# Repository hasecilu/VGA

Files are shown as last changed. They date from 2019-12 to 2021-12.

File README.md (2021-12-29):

# VGA adapter
This is a simple PCB board for interfacing a FPGA with SIL header to a VGA connector to add video functionalities to your projects.
Designed with [KiCad](https://kicad.org/download/)

[Download here](https://gitlab.com/hasecilu/VGA/-/archive/master/VGA-master.zip)

## Important!

For updates go to the [GitLab repo](https://gitlab.com/hasecilu/VGA)

## Pictures

First render
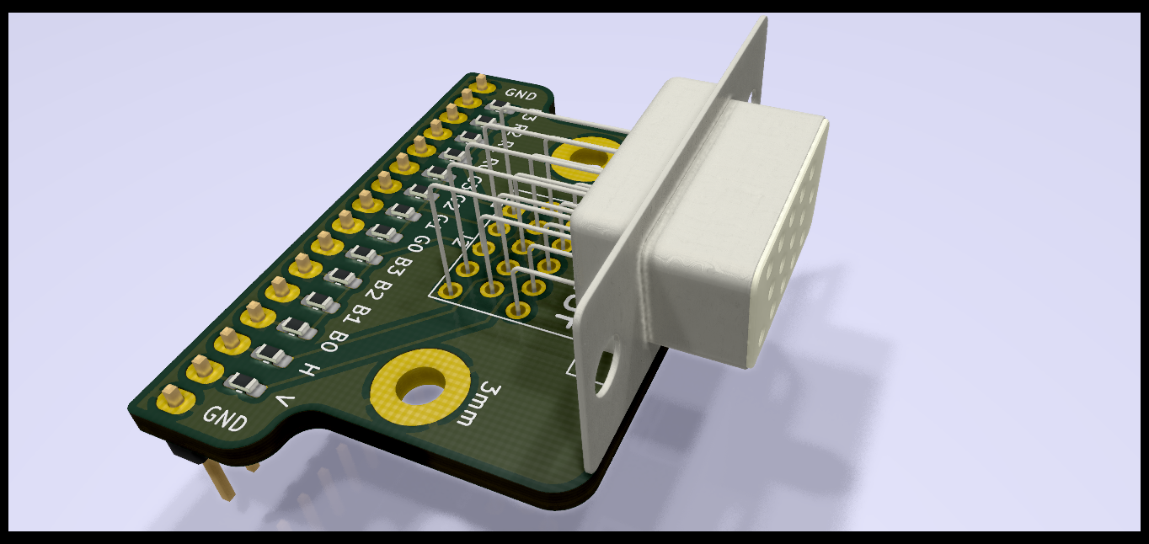
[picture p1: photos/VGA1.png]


Second render
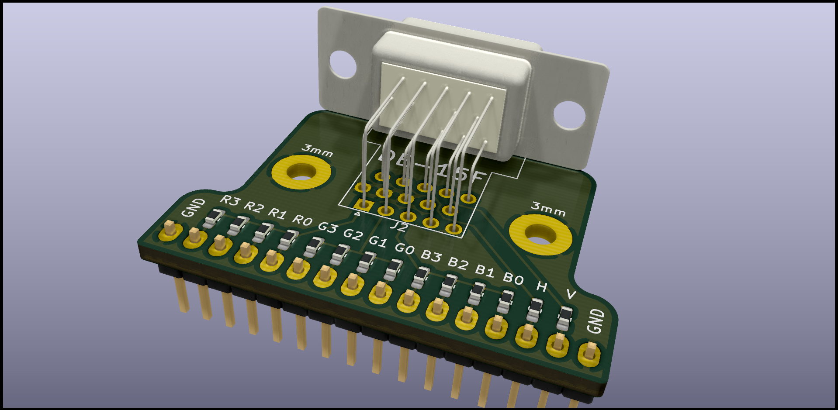
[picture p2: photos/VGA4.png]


Third render
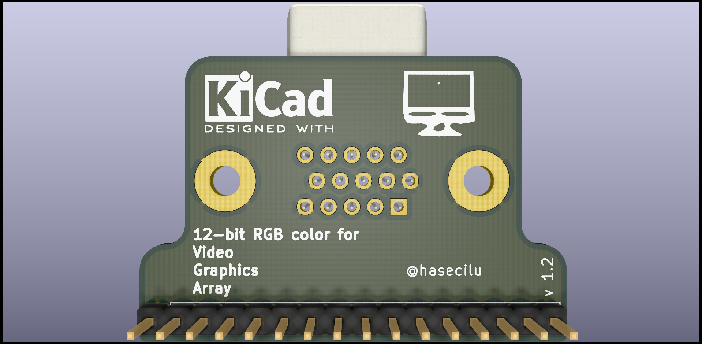
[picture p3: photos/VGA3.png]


Fourth render
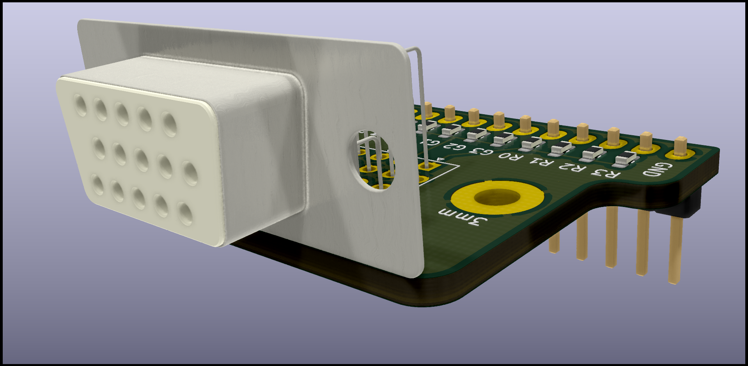
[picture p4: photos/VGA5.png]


Please note that the VGA board showed in the next pictures are from an older version and that's the reason there is a cable for connecting ground.
The new version has ground pins on both sides to avoid use cables (generally ground pins are at the begin/end of one SIL header in the development boards).

Perspective view
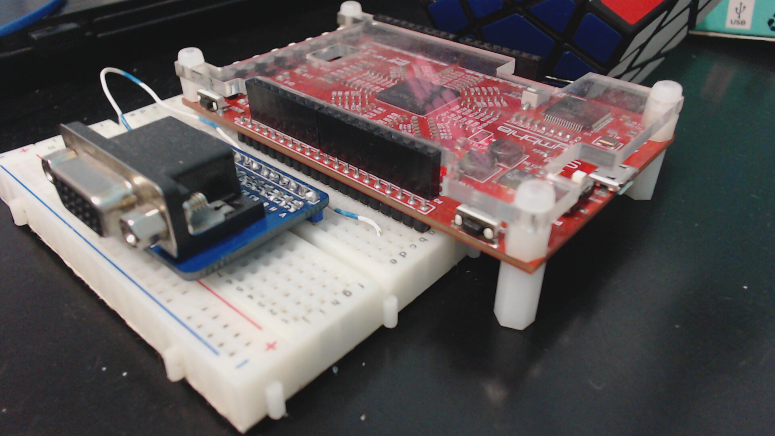
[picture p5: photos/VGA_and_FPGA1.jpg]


Top view
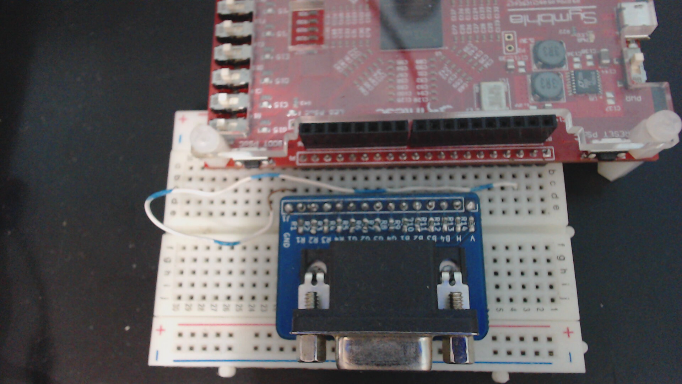
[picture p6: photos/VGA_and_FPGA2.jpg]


## Using the PCB

KiCad render (https://www.youtube.com/watch?v=zfjPtc4_cl0)

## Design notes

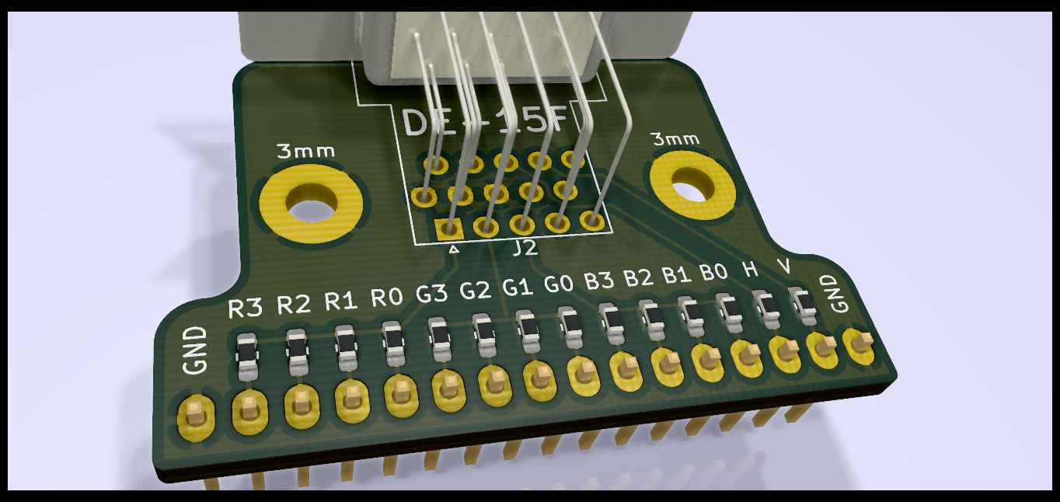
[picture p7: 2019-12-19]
photos/VGA2.png

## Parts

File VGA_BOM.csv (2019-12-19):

Source: | /home/uli/Documents/KiCAD/Boards/VGA/VGA.sch
Date: | Fri 13 Dec 2019 15:05:54 CST
Tool: | Eeschema 5.1.5-52549c5~84~ubuntu18.04.1
Generator: | /usr/share/kicad/plugins/bom_csv_grouped_by_value.py
Component Count: | 16
Individual Components:
Item | Qty | Reference(s) | Value | LibPart | Footprint | Datasheet
 |  | J1 | Conn_01x16 | Connector_Generic:Conn_01x16 | Connector_PinHeader_2.54mm:PinHeader_1x16_P2.54mm_Vertical | ~
 |  | J2 | DB15_Female_HighDensity | Connector:DB15_Female_HighDensity | Connector_Dsub:DSUB-15-HD_Female_Horizontal_P2.29x2.54mm_EdgePinOffset9.40mm | ~
 |  | R1 | 510 | Device:R | Resistor_SMD:R_0603_1608Metric_Pad1.05x0.95mm_HandSolder | ~
 |  | R2 | 1k | Device:R | Resistor_SMD:R_0603_1608Metric_Pad1.05x0.95mm_HandSolder | ~
 |  | R3 | 2k | Device:R | Resistor_SMD:R_0603_1608Metric_Pad1.05x0.95mm_HandSolder | ~
 |  | R4 | 4k | Device:R | Resistor_SMD:R_0603_1608Metric_Pad1.05x0.95mm_HandSolder | ~
 |  | R5 | 510 | Device:R | Resistor_SMD:R_0603_1608Metric_Pad1.05x0.95mm_HandSolder | ~
 |  | R6 | 1k | Device:R | Resistor_SMD:R_0603_1608Metric_Pad1.05x0.95mm_HandSolder | ~
 |  | R7 | 2k | Device:R | Resistor_SMD:R_0603_1608Metric_Pad1.05x0.95mm_HandSolder | ~
 |  | R8 | 4k | Device:R | Resistor_SMD:R_0603_1608Metric_Pad1.05x0.95mm_HandSolder | ~
 |  | R9 | 510 | Device:R | Resistor_SMD:R_0603_1608Metric_Pad1.05x0.95mm_HandSolder | ~
 |  | R10 | 1k | Device:R | Resistor_SMD:R_0603_1608Metric_Pad1.05x0.95mm_HandSolder | ~
 |  | R11 | 2k | Device:R | Resistor_SMD:R_0603_1608Metric_Pad1.05x0.95mm_HandSolder | ~
 |  | R12 | 4k | Device:R | Resistor_SMD:R_0603_1608Metric_Pad1.05x0.95mm_HandSolder | ~
 |  | R13 | 82 | Device:R | Resistor_SMD:R_0603_1608Metric_Pad1.05x0.95mm_HandSolder | ~
 |  | R14 | 82 | Device:R | Resistor_SMD:R_0603_1608Metric_Pad1.05x0.95mm_HandSolder | ~
Collated Components:
Item | Qty | Reference(s) | Value | LibPart | Footprint | Datasheet
1 | 1 | J1 | Conn_01x16 | Connector_Generic:Conn_01x16 | Connector_PinHeader_2.54mm:PinHeader_1x16_P2.54mm_Vertical | ~
2 | 1 | J2 | DB15_Female_HighDensity | Connector:DB15_Female_HighDensity | Connector_Dsub:DSUB-15-HD_Female_Horizontal_P2.29x2.54mm_EdgePinOffset9.40mm | ~
3 | 3 | R1, R5, R9 | 510 | Device:R | Resistor_SMD:R_0603_1608Metric_Pad1.05x0.95mm_HandSolder | ~
4 | 3 | R2, R6, R10 | 1k | Device:R | Resistor_SMD:R_0603_1608Metric_Pad1.05x0.95mm_HandSolder | ~
5 | 3 | R3, R7, R11 | 2k | Device:R | Resistor_SMD:R_0603_1608Metric_Pad1.05x0.95mm_HandSolder | ~
6 | 3 | R4, R8, R12 | 4k | Device:R | Resistor_SMD:R_0603_1608Metric_Pad1.05x0.95mm_HandSolder | ~
7 | 2 | R13, R14 | 82 | Device:R | Resistor_SMD:R_0603_1608Metric_Pad1.05x0.95mm_HandSolder | ~

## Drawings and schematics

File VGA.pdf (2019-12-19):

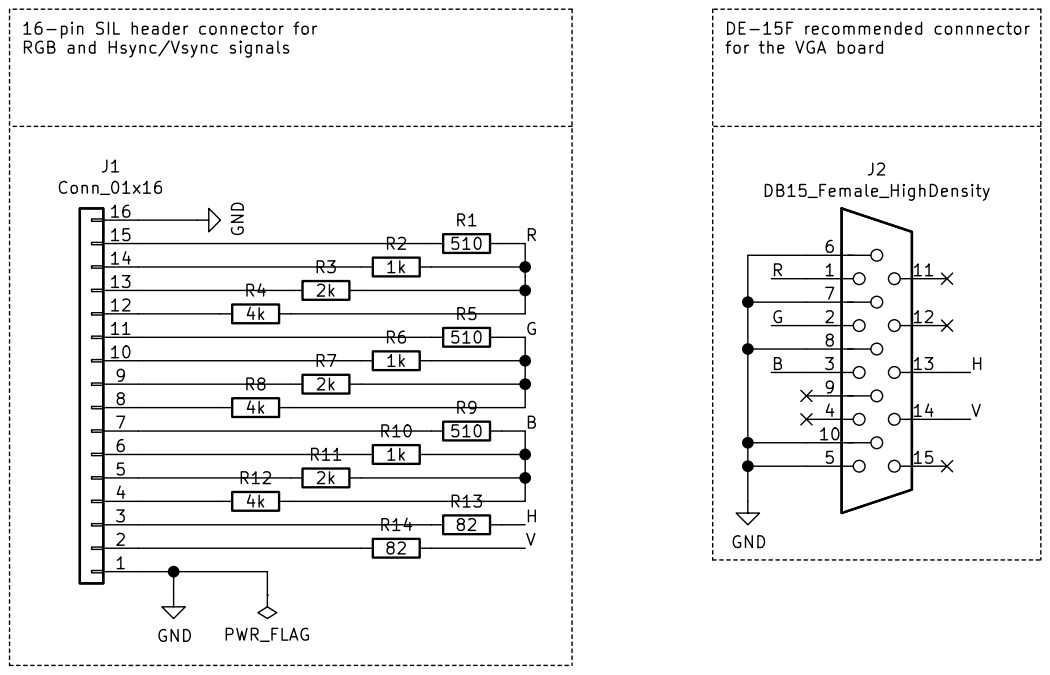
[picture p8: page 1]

16-pin SIL header connector for
RGB and Hsync/Vsync signals

V DE-15F recommended connnector
for the VGA board

12 bits per pixel (bpp) 2¹²=4096 different colors R4

2=16 different red, green and blue tonalities
4 bits per color channel/sample (bps)
File: VGA.sch Sheet: / Ulices AH

Id: 1/1 Title: 12-bit RGB color for VGA module / 4-bit color depth

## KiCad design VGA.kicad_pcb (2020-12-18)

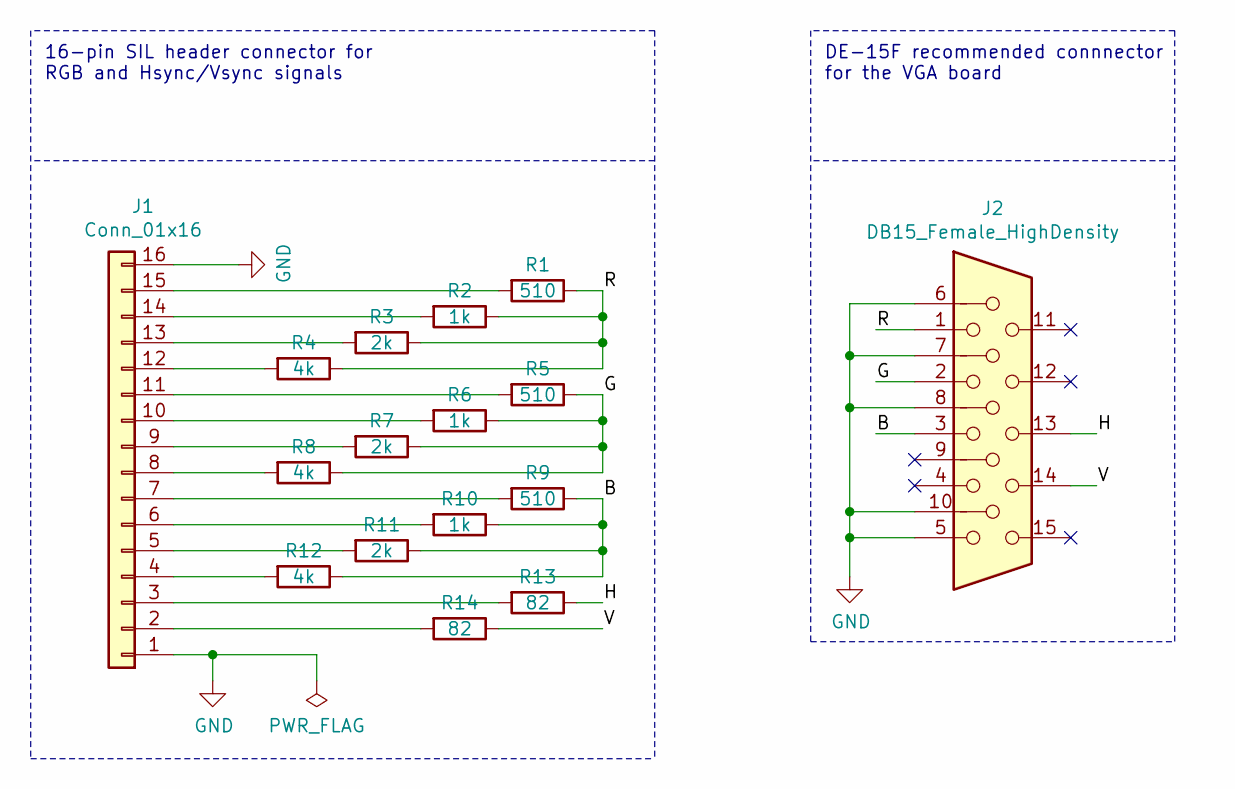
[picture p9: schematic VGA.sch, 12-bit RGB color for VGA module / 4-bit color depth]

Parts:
J1: Conn_01x16; PinHeader_1x16_P2.54mm_Vertical
J2: DB15_Female_HighDensity; DSUB-15-HD_Female_Horizontal_P2.29x2.54mm_EdgePinOffset9.40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
R1, R5, R9: 510; R_0603_1608Metric_Pad1.05x0.95mm_HandSolder
R2, R6, R10: 1k; R_0603_1608Metric_Pad1.05x0.95mm_HandSolder
R3, R7, R11: 2k; R_0603_1608Metric_Pad1.05x0.95mm_HandSolder
R4, R8, R12: 4k; R_0603_1608Metric_Pad1.05x0.95mm_HandSolder
R13, R14: 82; R_0603_1608Metric_Pad1.05x0.95mm_HandSolder

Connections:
/B: J2.3, R9.1, R10.1, R11.1, R12.1
/G: J2.2, R5.1, R6.1, R7.1, R8.1
/H: J2.13, R13.1
/R: J2.1, R1.1, R2.1, R3.1, R4.1
/V: J2.14, R14.1
GND: J1.1, J1.16, J2.5, J2.6, J2.7, J2.8, J2.10; also elsewhere on the board
unnamed: J1.2, R14.2
unnamed: J1.3, R13.2
unnamed: J1.4, R12.2
unnamed: J1.5, R11.2
unnamed: J1.6, R10.2
unnamed: J1.7, R9.2
unnamed: J1.8, R8.2
unnamed: J1.9, R7.2
unnamed: J1.10, R6.2
unnamed: J1.11, R5.2
unnamed: J1.12, R4.2
unnamed: J1.13, R3.2
unnamed: J1.14, R2.2
unnamed: J1.15, R1.2

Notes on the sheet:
DE-15F recommended connnector for the VGA board
16-pin SIL header connector for RGB and Hsync/Vsync signals

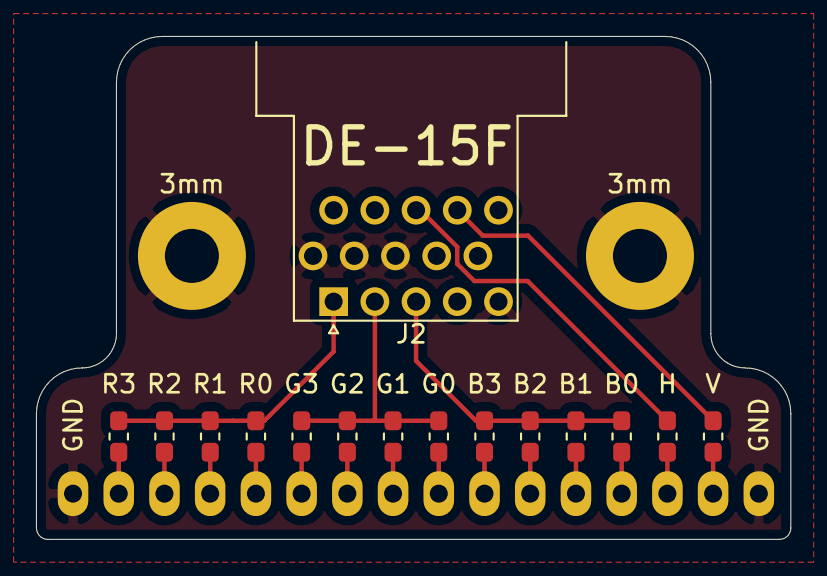
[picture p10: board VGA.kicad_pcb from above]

Board: 2 copper layers, 41.9 x 27.9 mm, 18 parts (1 on the bottom side), 20 nets.

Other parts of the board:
3mm, 3mm#2: MountingHole_3mm_Pad

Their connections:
GND: 3mm.1, 3mm#2.1; also elsewhere on the board

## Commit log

2019-12-19 First public release
    This is the first version I release
    [VGA-B_Cu.gbr, VGA-B_Mask.gbr, VGA-B_Paste.gbr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]
2020-12-18 Small changes
    [VGA-B_Cu.gbr, VGA-B_Mask.gbr, VGA-B_Paste.gbr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]
